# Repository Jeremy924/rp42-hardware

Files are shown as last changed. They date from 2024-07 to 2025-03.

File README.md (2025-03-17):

# RP-42
The goal of RP-42 is to develop an affordable calculator that can run [Free42](https://github.com/Jeremy924/free42). The target cost for this was initially $20, but the final calculator costs slightly under $30. <br>
The calculator uses a STM32L475 microcontroller connected to a 8MB QSPI Flash. The operating system is stored on the STM32's internal 256KB Flash, while the Free42 application code is stored on the external flash drive. The QSPI interface can be memory mapped on the STM32, so the application code can be executed on the flash drive without copying to the RAM. 
<br><br>
More information about RP-42 can be found on the RP-42 website [here](https://jeremy924.github.io/rp42/index.html).

## Development Timeline
07/06/2024 - Started designing PCB<br>
07/29/2024 - Completed PCB 0.0.4, and ordered PCB through JLCPCB<br>
08/04/2024 - Used Raspberry PI Zero 2W and ESP32-S3 to display Free42 on the LCD screen used in the calculator<br>
08/05/2024 - Began assemblying and testing<br>
08/11/2024 - STM32 communicates through micro USB port for the first time<br>
08/11/2024 - Test code is executed on the microcontroller, which showed that all the buttons and the LCD were working correctly. <br>

<br>
<i>In the test shown above, whenever a key is pressed, the number corresponding to the key that was pressed was displayed on the screen. The image shows that all the buttons were read correctly by the microcontroller.</i>
<br>The jumper wire in the image above is used to connect the UART RX pin to either GND or 3V. In the original PCB design, the BOOT0 pin on the STM32 was directly connected to 3V, however this did
not work because BOOT0 must be low in order to execute user code, even if the USB DFU is used to execute code. To correct this issue, the trace connected to the BOOT0 was broken, and the trace connected to the UART RX pin was broken. Because the traces were very close to each other, some solder was used to bridge the gap between the UART port and the BOOT0 pin. This way, the UART RX connector could be 
used to pull BOOT0 to low or high. 
<br><br>
08/21/2024 - STM32 can read and write to Flash drive through QSPI interface. <br>
08/21/2024 - Set up basic command line interface over USB VCP to make debugging easier, and created "frw" (flash read-write tool) to control flash. <br>

<br><i>In the test shown above, the flash read-write tool was used to write "Hello world" to the flash and then read it back. The test shows that the hardware and software for the flash is working correctly</i><br>
12/10/2024 - Complete 0.0.5 and order PCB <b>with SWD port</b><br>
01/22/2025 - Ran Free42 on RP42. <br>

<br>

## Schematics for 0.0.5
### Top Module

### Keyboard

### Screen

### MCU

### Power Components

### PCB 0.0.5


## Hardware Changes for version 0.0.6
- [ ] Move COL0 input to a pin supporting powerdown interrupt.
## Hardware Changes for version 0.0.5
- [X] Add pad for battery terminal
      - temporary solution for 0.0.4: scrape off surface to access battery trace
- [X] Add button for BOOT0
      - temporary solution for 0.0.4: break current BOOT0 trace and connect it to backup RX trace. Then use RX connector to pull BOOT0 either high or low.
- [X] Add button for RES
      - temporary solution for 0.0.4: disconnect power.
- [X] **Add debug port**
- [X] move buttons closer together
- [X] connect VBAT to 3V rather than directly to battery. In its current state, if USB is connected and battery is not, then VBAT will be 0V, which is outside of recommended operating conditions.
- [X] move components further away from battery so that battery does not hit them if pushed in too far
- [X] add pull up resistor for external flash NCS pin so that it is pulled high while STM32 is booting.
- [X] add pull up resistor for on button so that mcu can be powered off and button will still be able to trigger interrupt

### Software Status
RP-42 is able to perform all mathematical operations in Free42. See (Free42)[github.com/Jerem924/free42) for current status.

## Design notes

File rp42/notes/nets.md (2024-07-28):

# Power Supplies
**VBAT** - 2.7V-3V: power directly from battery<br>
**GND**  - 0V<br>
**3V**   - 2.7V-3V: regulated voltage from USB/battery for mcu<br>
**3V PERPH** - 2.7V-3V: regulated voltage from USB/battery for peripherals<br>
**5V USB**    - 5V: power directly from USB<br>
**3V-5V**     - 2.7V-5V: unregulated power selected from USB if available or battery

# Nets:
### PWR_PERPH
Connections: *mcu* (pin 61/PB8, out), *U5* (PSU, in), R2(PSU,in)<br>
Enables power for the flash and the screen. <br>
Pulled down by a 100K resistor. The output from the mcu
can be in 3 states, high (enable peripherals),
high impedance (pulled low by resistor), or off (also pulled low by resistor).
The mcu pin should not be set to low could possibly be higher than 0V, which would
leak current.
### COL[0..5]
Connections: input_matrix (all buttons, out), mcu(pins 8-11,24,25/PC0-PC6, in)<br>
Pins are normally high impedance, so they should be pulled low by the mcu. If button is
pressed while mcu is scanning keyboard, then high output from ROW will pull the pin high.
### ROW[0..6]
Connections: input_matrix (all buttons, in), mcu(pins 13-20,31,43/PA0-PA4,PA8,PA10,out)<br>
Pins should normally be high impedance, except when scanning. When scanning, all pins should be 
low except for the pin that is currently being scanned. 
### ~RES
Connections: U1 (pin 39,in),mcu(pin 35/PB14,out)<br>
Used to reset the screen
### ~CS
Connections: U1 (pin 40,in),mcu(pin 34/PB13,out)<br>
Used to select the screen. This will probably always be low.
### ~A0
Connections: U1 (pin 38,in),mcu(pin 33/PB12,out)<br>
Used to select the address or data mode of the screen.
### SCL
Connections: U1 (pin 37,in),mcu(pin 51/PC10,out)<br>
Used to clock data into the screen.
### SI
Connections: U1 (pin 36,in),mcu(pin 53/PC12,out)<br>
Used to send data to the screen.
### D-
Connections: mcu (pin 44/PA11,io), CR1(pin 3,io)<br>
USB minus data. 
### D+
Connections: mcu (pin 45/PA12,io), CR1(pin 1,io)<br>
USB plus data.
### FLASH_IO[0..3]
Connections: mcu (pin 27/PB1,pin 26/PB0,pin 23/PA7,pin 22/PA6,io), U3(pin 5,2,3,7,io)<br>
Used to communicate with the flash chip.
### FLASH_NCS
Connections: mcu (pin 30/PB11,out), U3(pin 1,in)<br>
Used to select the flash chip.
### FLASH_CLK
Connections: mcu (pin 29/PB10,out), U3(pin 6,in)<br>
Used to clock data into the flash chip.
### D- IN
Connections: J1 (pin 2,io), CR1 (pin 4,io)<br>
USB minus data input. This is sent to the esd protection chip before 
going to the mcu.
### D+ IN
Connections: J1 (pin 3,io), CR1 (pin 6,io)<br>
USB plus data input. This is sent to the esd protection chip before
going to the mcu.

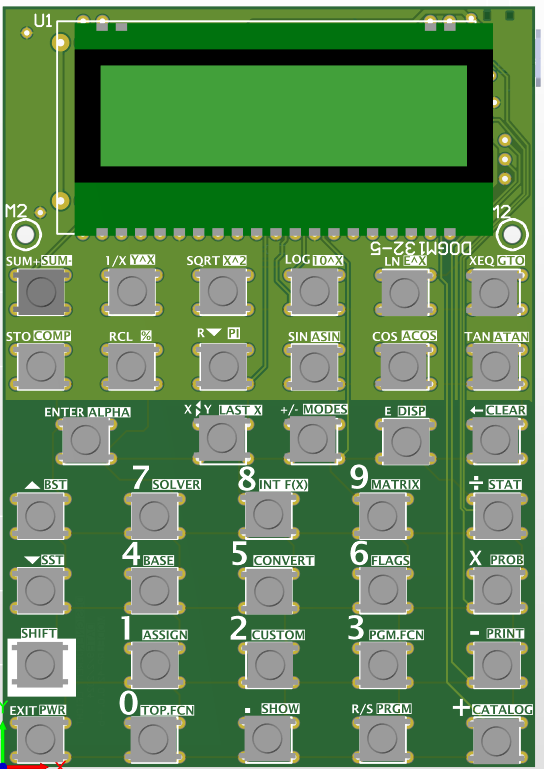
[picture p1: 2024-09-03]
docs/img/altuim-3d-front.png

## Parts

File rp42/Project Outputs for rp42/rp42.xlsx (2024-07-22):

Line # | Name | Description | Designator | Quantity | Manufacturer 1 | Manufacturer Part Number 1 | Manufacturer Lifecycle 1 | Supplier 1 | Supplier Part Number 1 | Supplier Unit Price 1 | Supplier Subtotal 1
 | 1uF | CL10B105KP8NNNC | C1, C2, C3, C4, C5, C6, C7, C8, C9, C10, C17, C18, C19, C20 | 14
 | 20pF | SMD Capacitor C0G(EIA) with Capacitance: 20pF Tol. 5%. Rated Voltage: 50Vdc GRM0335C1H200JA01D | C11, C12 | 2
 | 100nF | 0.1ÂµF Â±10% 10V Ceramic Capacitor X7R 0402 _1005 Metric_ | C13, C14, C15, C16 | 4
 | USBLC6-4SC6 | No Description Available | CR1 | 1
 | 10118192-0002LF | Micro USB 2.0, Input Output Connectors, B TYPE RECEPTACLE without flange | J1 | 1
 | 470R | RC0402FR-07470RL 470R smd resistor | R1 | 1
 | 100K | RC0402FR-07100KL | R2 | 1
 | temp_switch |  | S1, S2, S3, S4, S5, S6, S7, S8, S9, S10, S11, S12, S13, S15, S16, S17, S18, S19, S20, S21, S22, S23, S24, S25, S26, S27, S28, S29, S30, S31, S32, S33, S34, S35, S36, S37, S38, S39, S40, S41, S42 | 41
 | INTERFACE |  | U1 | 1
 | STM32L475RCT3 | No Description Available | U2 | 1
 | W25Q64JVSSIQ | No Description Available | U3 | 1
 | MIC5365-3.0YC5-TR | 3V Linear Voltage Regulator | U4, U6 | 2
 | TPS2115PW | 2.8-V to 5.5-V, 84-m&Omega;, 1.25-A, power mux with manual, automatic, slow switchover and status | U5 | 1
 | 8.000MHZ | HC/49US (AT49) SMD LOW PROFILE CRYSTAL ABLS-8.000MHZ-B4-T | Y1 | 1

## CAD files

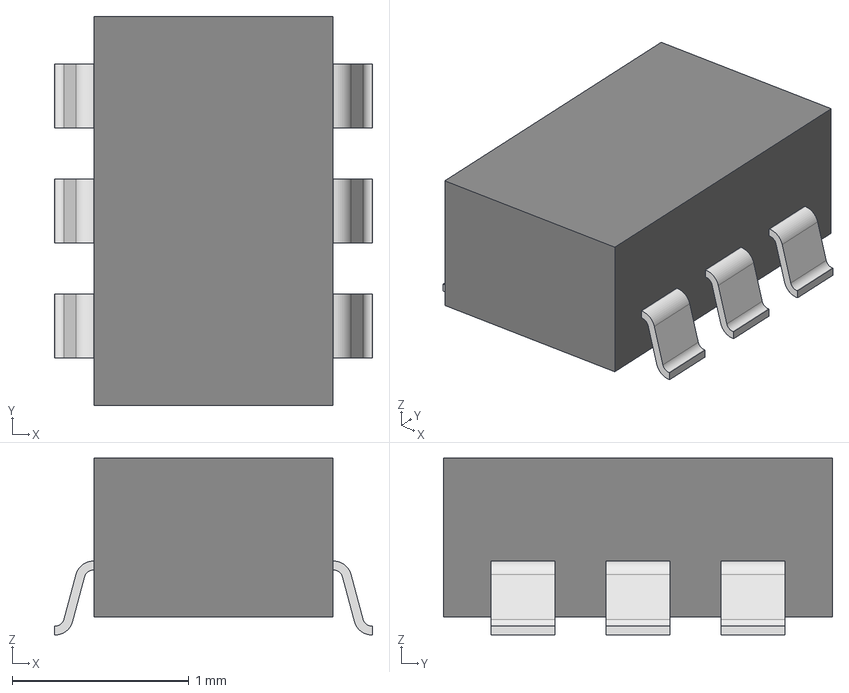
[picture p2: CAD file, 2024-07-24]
rp42/BAT54DW_7_F/AltiumDesigner/SOT-363_DIO.step
1.80 x 2.20 x 1.00 mm

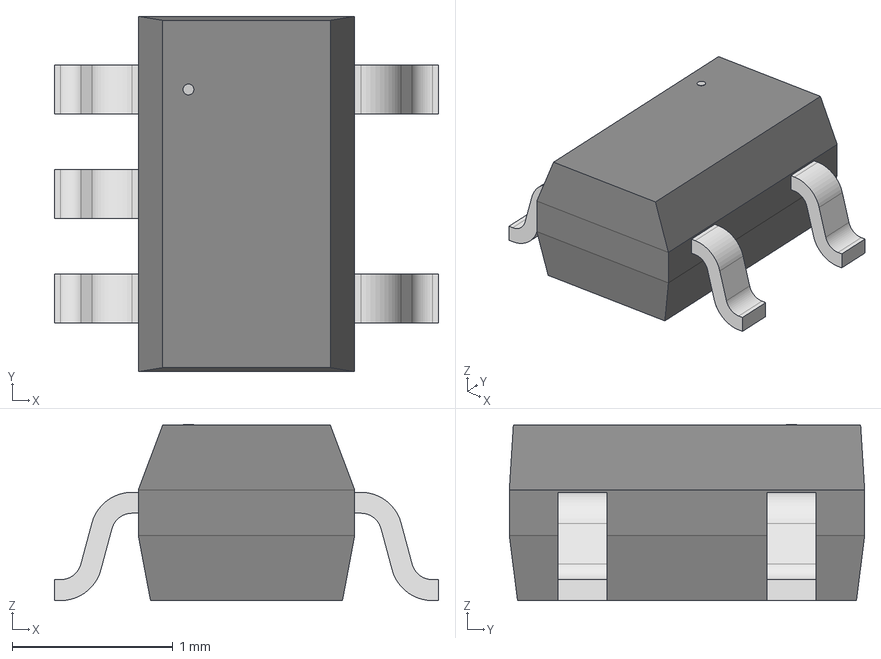
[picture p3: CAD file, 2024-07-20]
rp42/MIC5365_3_0YC5_TR/AltiumDesigner/SC-70_C5_MCH.step
2.39 x 2.21 x 1.09 mm

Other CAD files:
rp42/BAT54DW_7_F/SOT-363_DIO.stl
rp42/MIC5365_3_0YC5_TR/SC-70_C5_MCH.stl

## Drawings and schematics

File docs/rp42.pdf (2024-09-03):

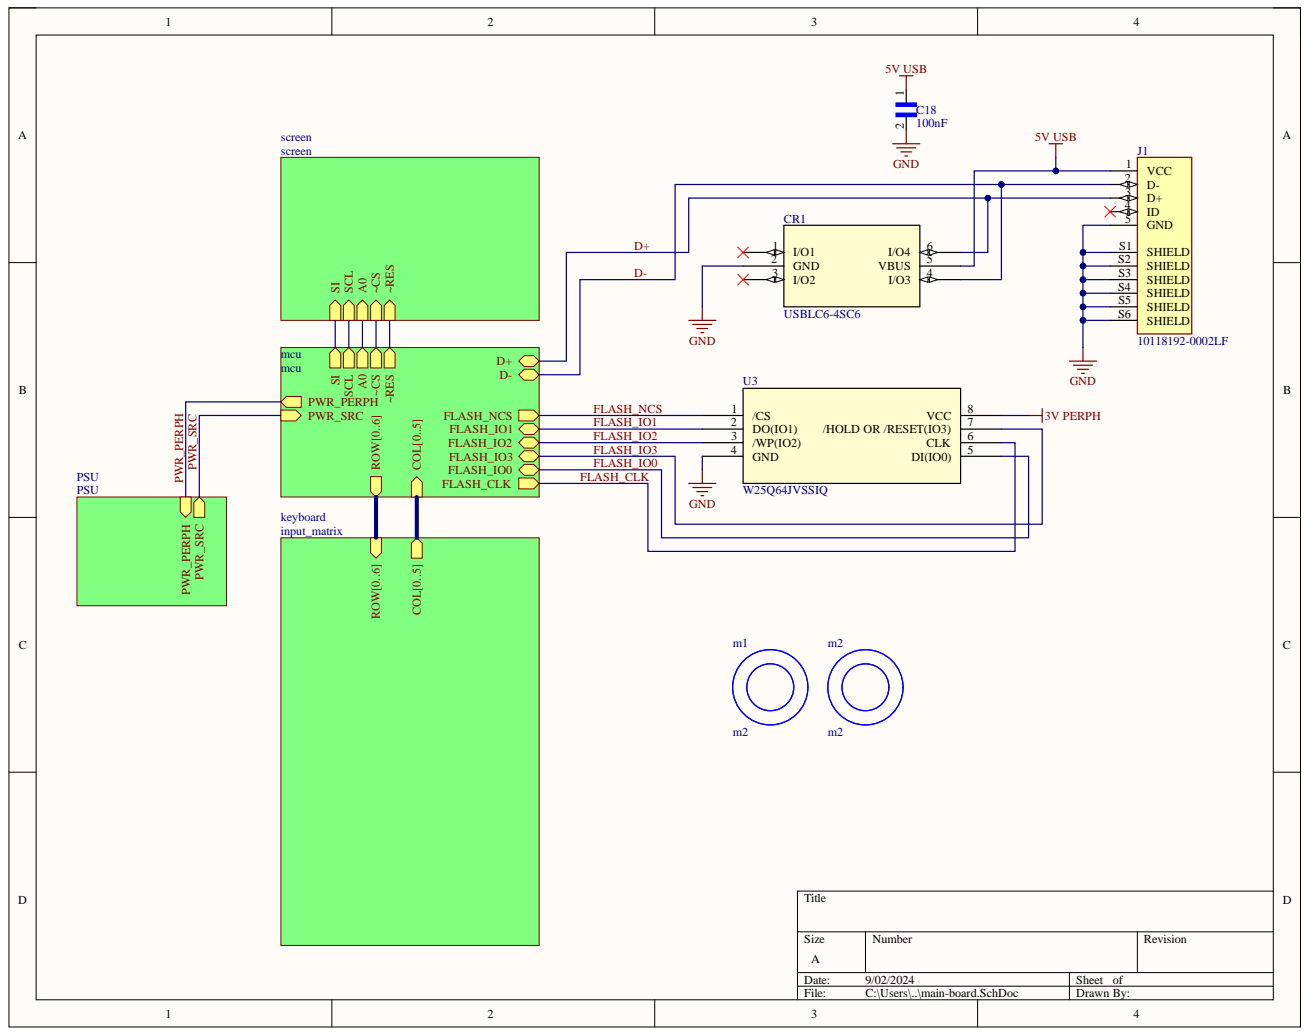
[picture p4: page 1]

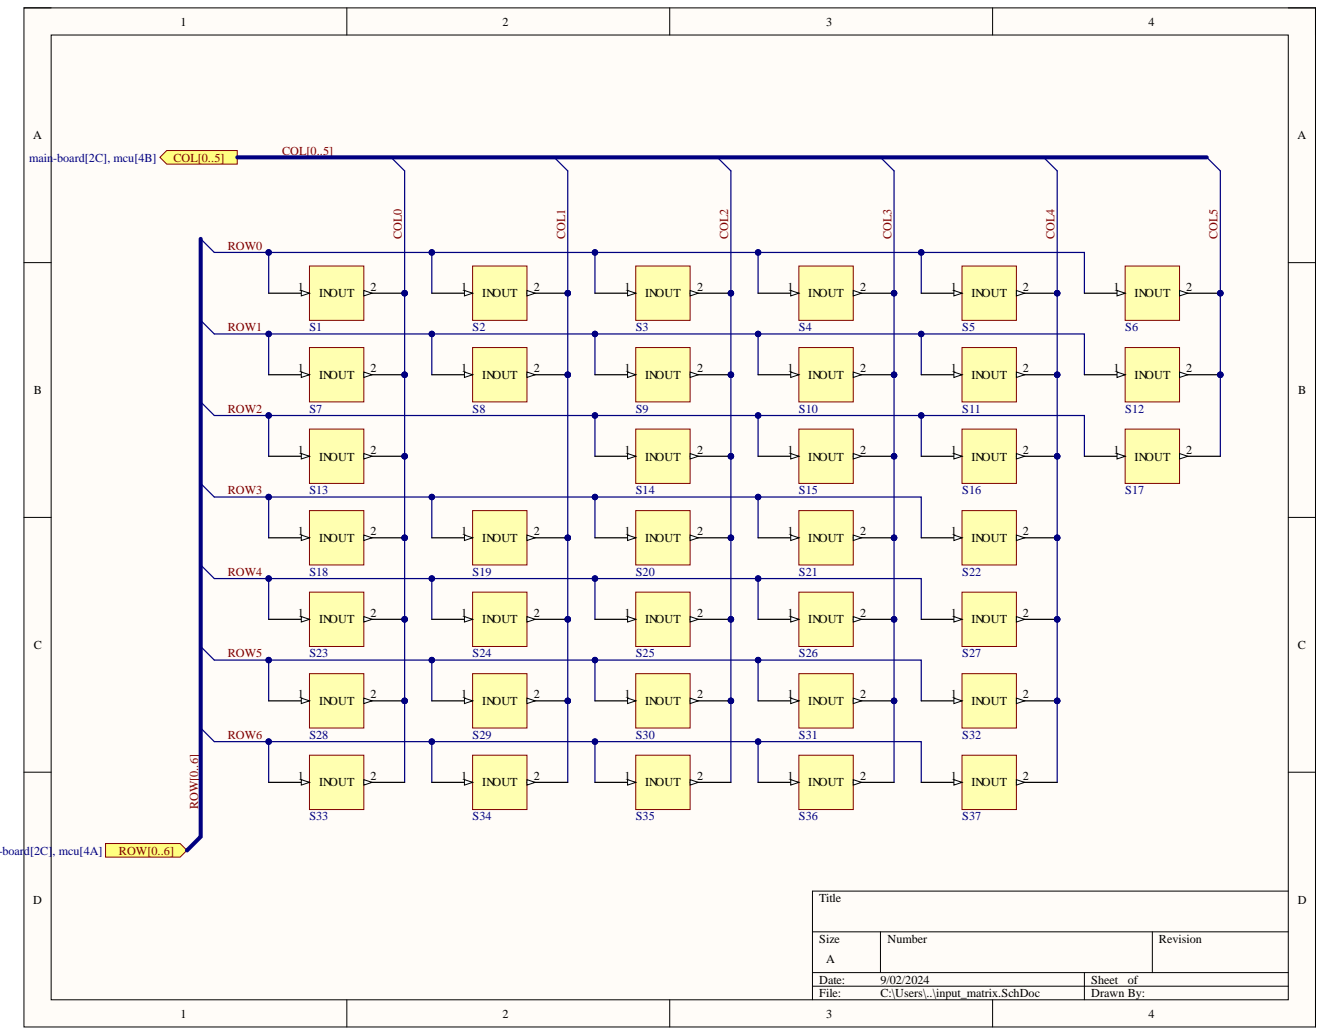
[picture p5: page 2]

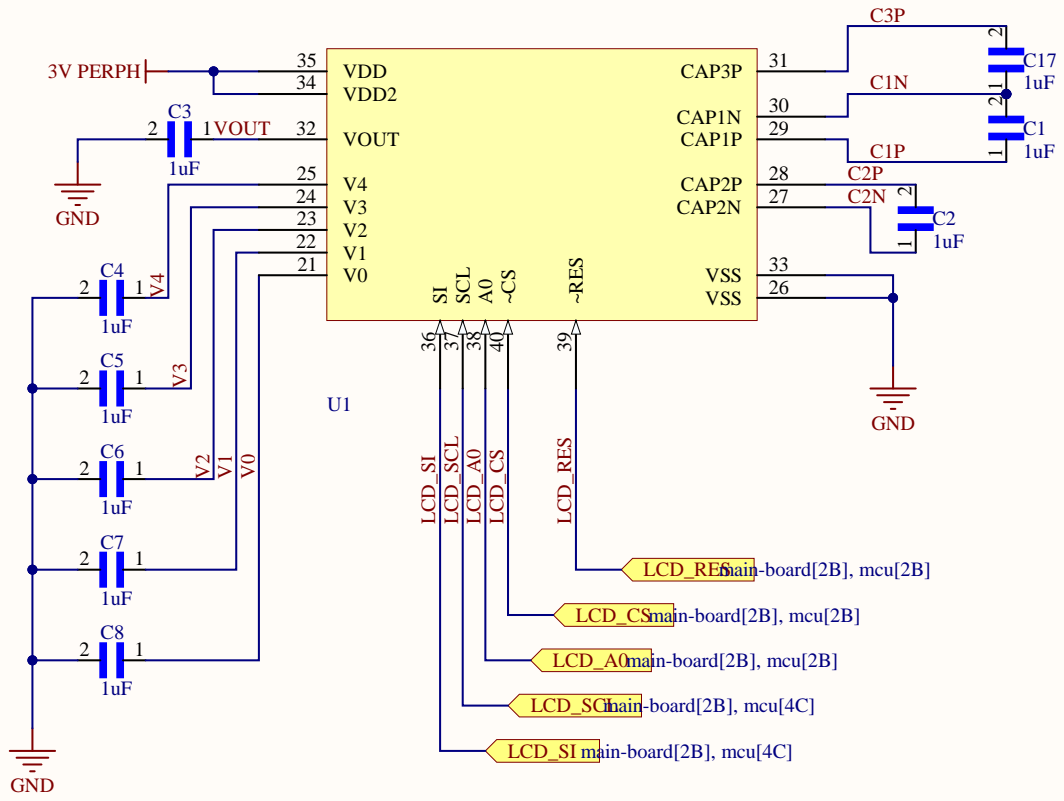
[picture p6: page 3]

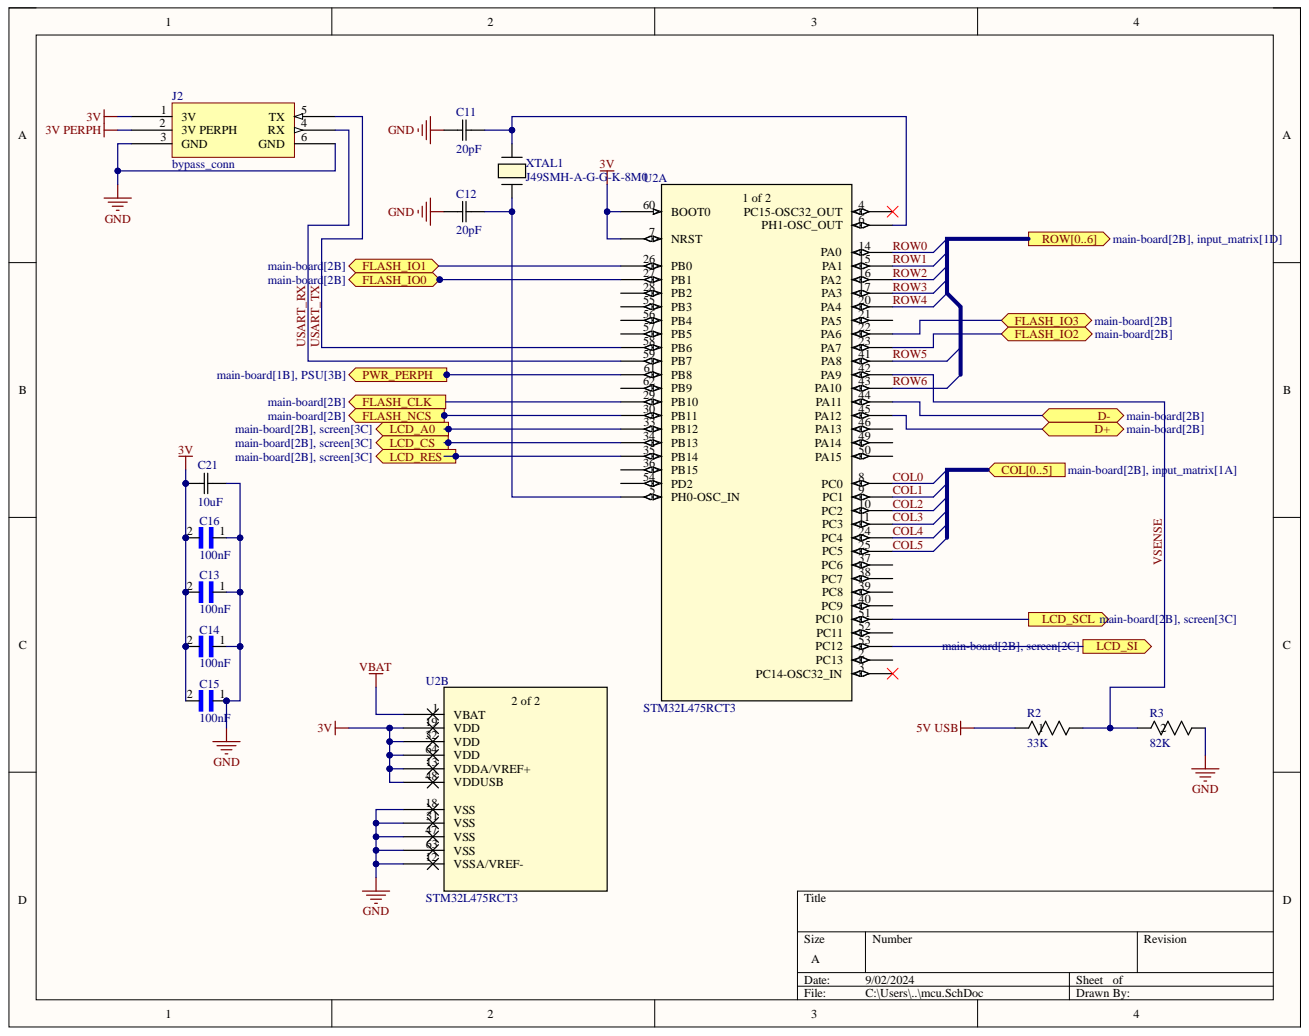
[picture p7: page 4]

PB9 62 | ROW6

PB13 34
PB14 35
PB15 36

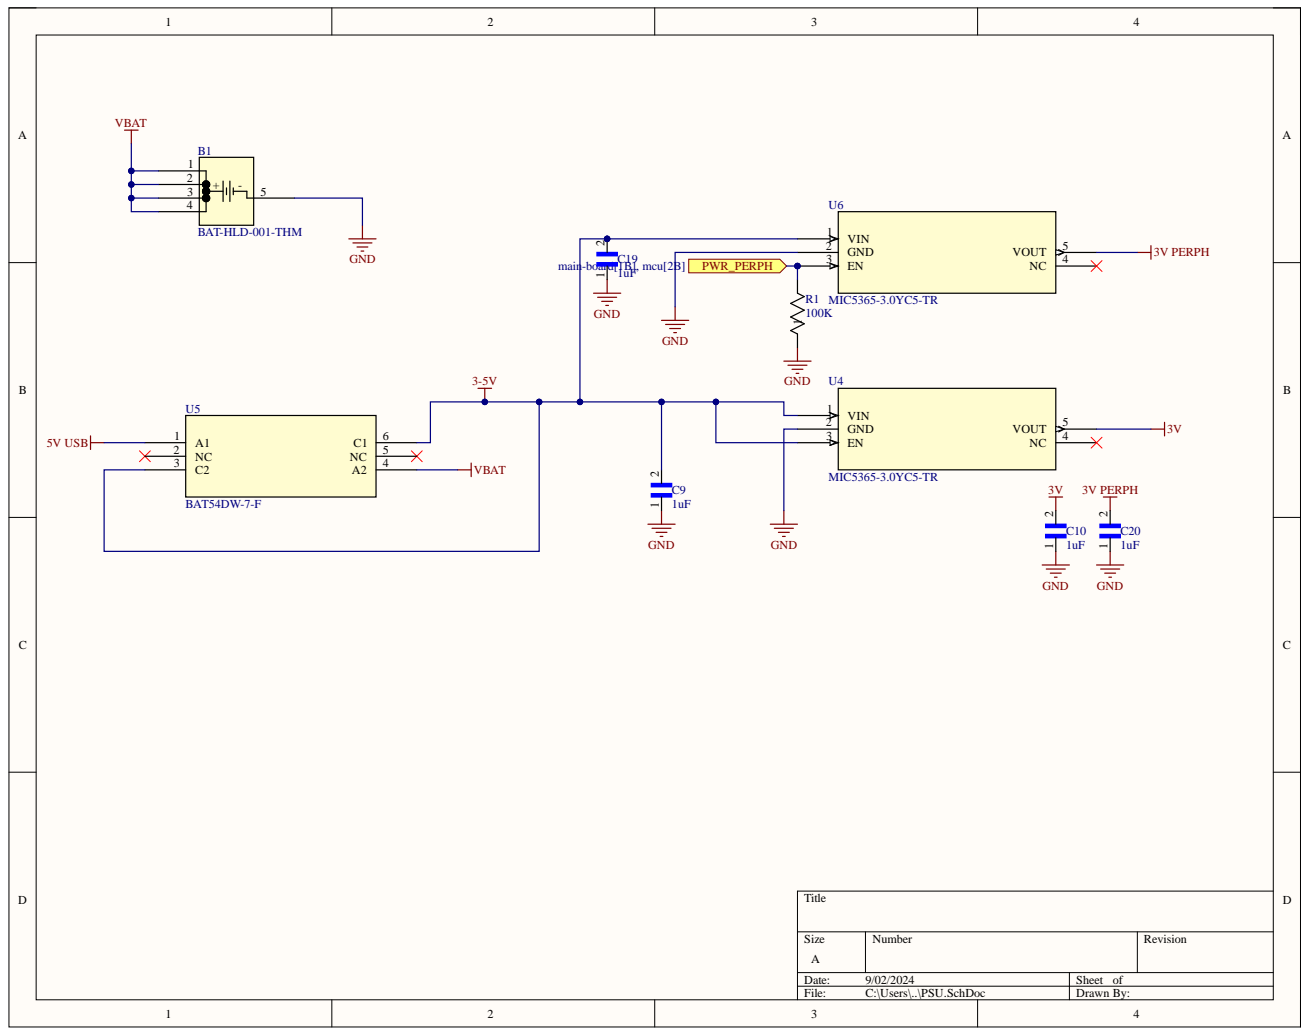
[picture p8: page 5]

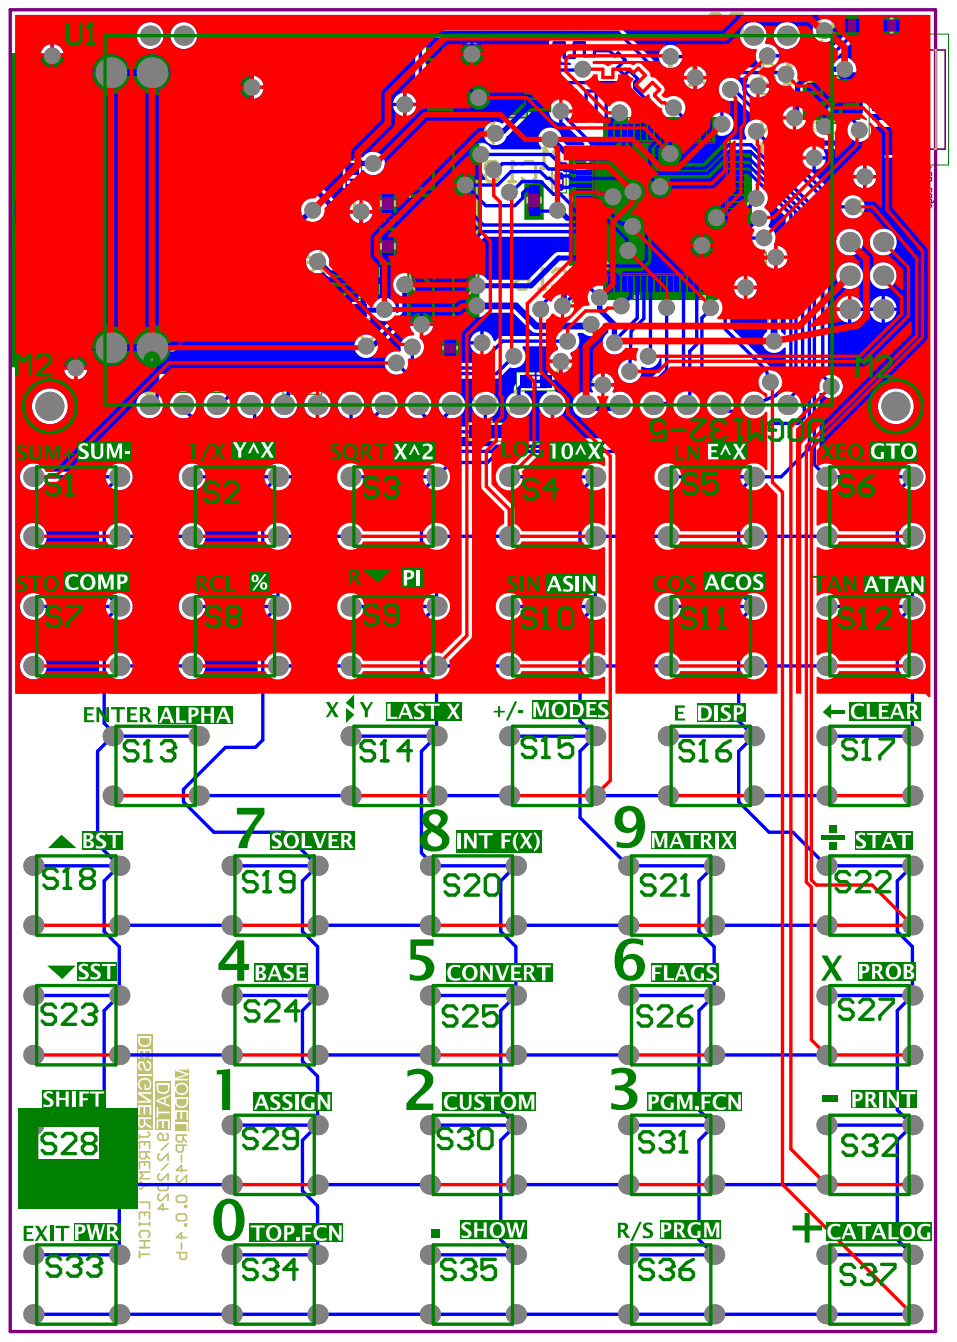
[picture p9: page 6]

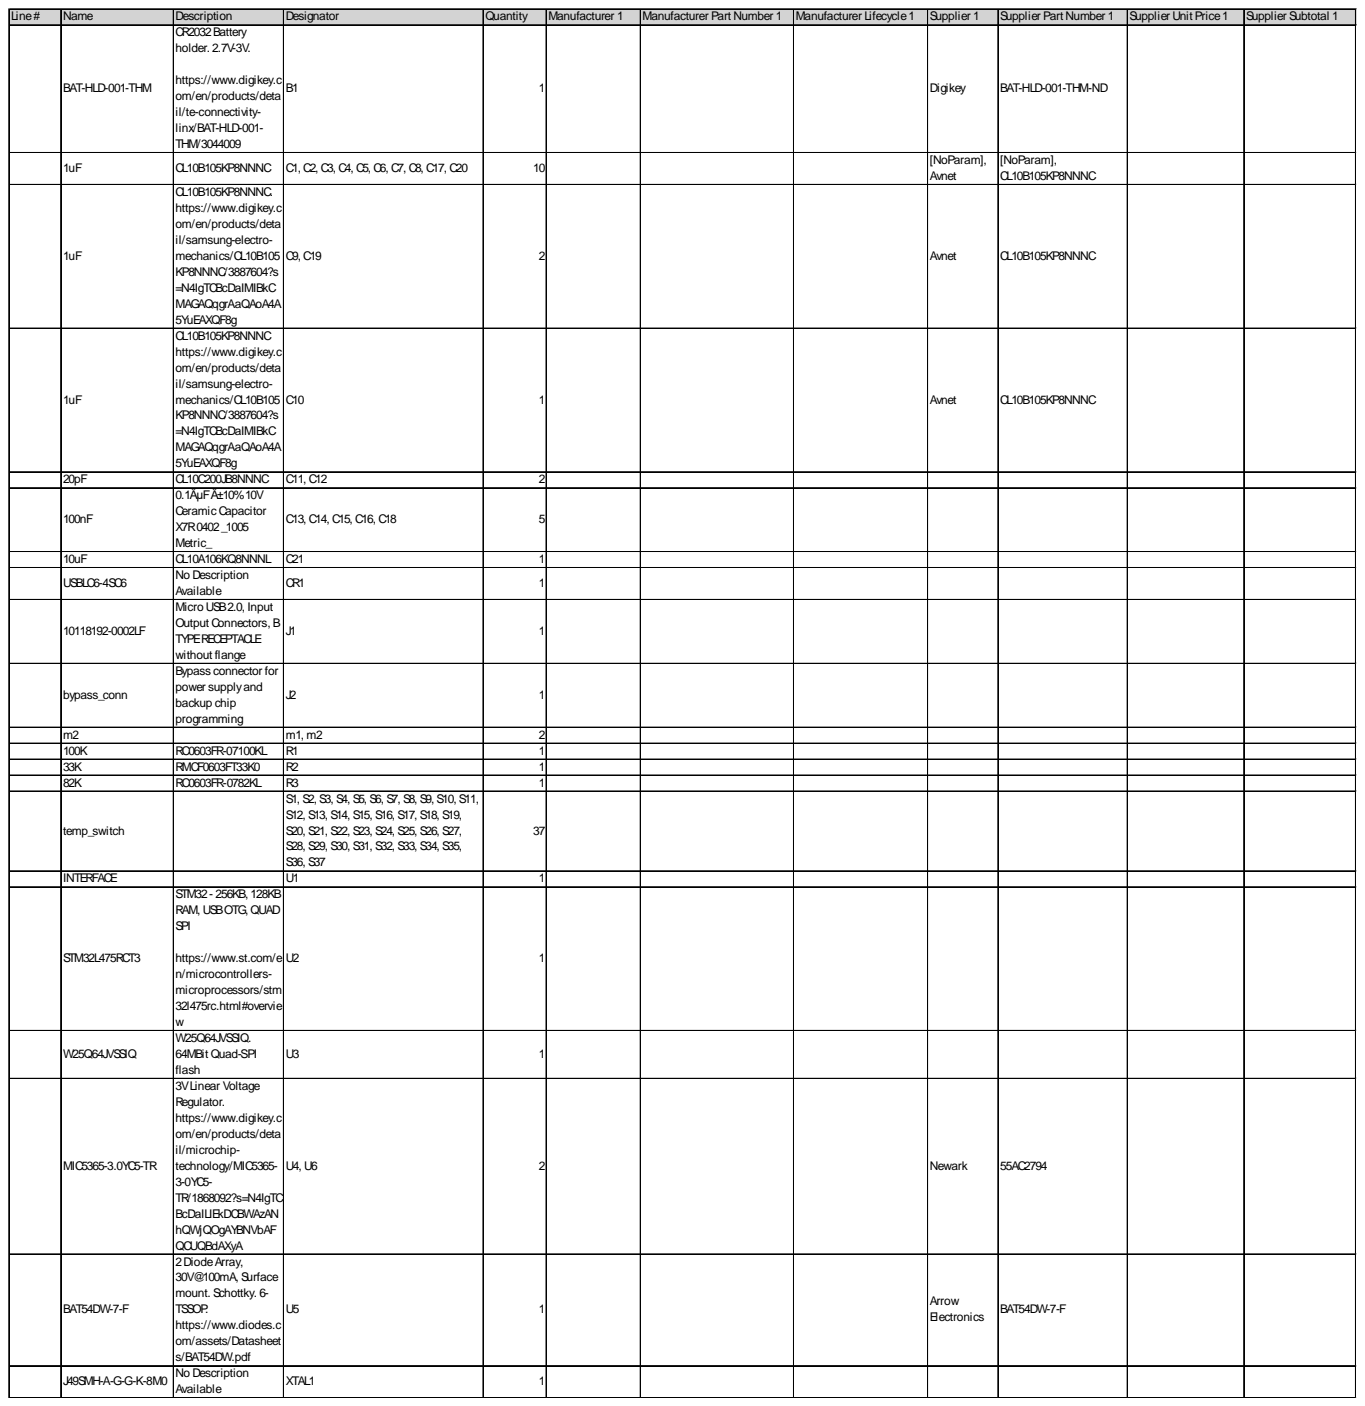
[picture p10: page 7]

Line# | Name | Description | Designator | Quantity | Manufacturer 1 | Manufacturer Part Number 1 | Manufacturer Lifecycle1 | Supplier 1 | Supplier Part Number 1 | Supplier Unit Price1 | Supplier Subtotal 1

BAT-HLD-001-THM | CR2032Battery holder. 2.7V-3V. https://www.digikey.com/en/products/detail/te-connectivity-linx/BAT-HLD-001-THM/3044009 | B1 | 1 | | | | Digikey | BAT-HLD-001-THM-ND

1uF | CL10B105KP8NNNC | C1, C2, C3, C4, C5, C6, C7, C8, C17, C20 | 10 | | | | [NoParam], Avnet | [NoParam], CL10B105KP8NNNC

1uF | CL10B105KP8NNNC. https://www.digikey.com/en/products/detail/samsung-electro-mechanics/CL10B105KP8NNNC/3887604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 MAGAQqgrAaQAoA4A 5YuEAXQF8g | C9, C19 | 2 | | | | Avnet | CL10B105KP8NNNC

1uF | CL10B105KP8NNNC https://www.digikey.com/en/products/detail/samsung-electro-mechanics/CL10B105KP8NNNC/3887604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 MAGAQqgrAaQAoA4A 5YuEAXQF8g | C10 | 1 | | | | Avnet | CL10B105KP8NNNC

20pF | CL10C200JB8NNNC | C11, C12 | 2
100nF | 0.1ÂµFÂ±10%10V Ceramic Capacitor X7R0402_1005 Metric_ | C13, C14, C15, C16, C18 | 5

10uF | CL10A106KQ8NNNL | C21 | 1
USBLC6-4SC6 | No Description Available | CR1 | 1

10118192-0002LF | Micro USB2.0, Input Output Connectors, B TYPERECEPTACLE without flange | J1 | 1

bypass_conn | Bypass connector for power supplyand backup chip programming | J2 | 1

m2 | | m1, m2 | 2
100K | RC0603FR-07100KL | R1 | 1
33K | RMCF0603FT33K0 | R2 | 1
82K | RC0603FR-0782KL | R3 | 1
temp_switch | | S1, S2, S3, S4, S5, S6, S7, S8, S9, S10, S11, S12, S13, S14, S15, S16, S17, S18, S19, S20, S21, S22, S23, S24, S25, S26, S27, S28, S29, S30, S31, S32, S33, S34, S35, S36, S37 | 37

INTERFACE | | U1 | 1
STM32L475RCT3 | STM32- 256KB, 128KB RAM, USBOTG, QUAD SPI https://www.st.com/en/microcontrollers-microprocessors/stm 32l475rc.html#overvie w | U2 | 1

W25Q64JVSSIQ | W25Q64JVSSIQ. 64MBit Quad-SPI flash | U3 | 1

MIC5365-3.0YC5-TR | 3VLinear Voltage Regulator. https://www.digikey.com/en/products/detail/microchip-technology/MIC5365-3-0YC5-TR/1868092?s=N4IgTC BcDaILIEkDCBWAzAN hQWjQOgAYBNVbAF QCUQBdAXyA | U4, U6 | 2 | | | | Newark | 55AC2794

BAT54DW-7-F | 2DiodeArray, 30V@100mA, Surface mount. Schottky. 6-TSSOP. https://www.diodes.com/assets/Datasheets/BAT54DW.pdf | U5 | 1 | | | | Arrow Electronics | BAT54DW-7-F

J49SMH-A-G-G-K-8M0 | No Description Available | XTAL1 | 1

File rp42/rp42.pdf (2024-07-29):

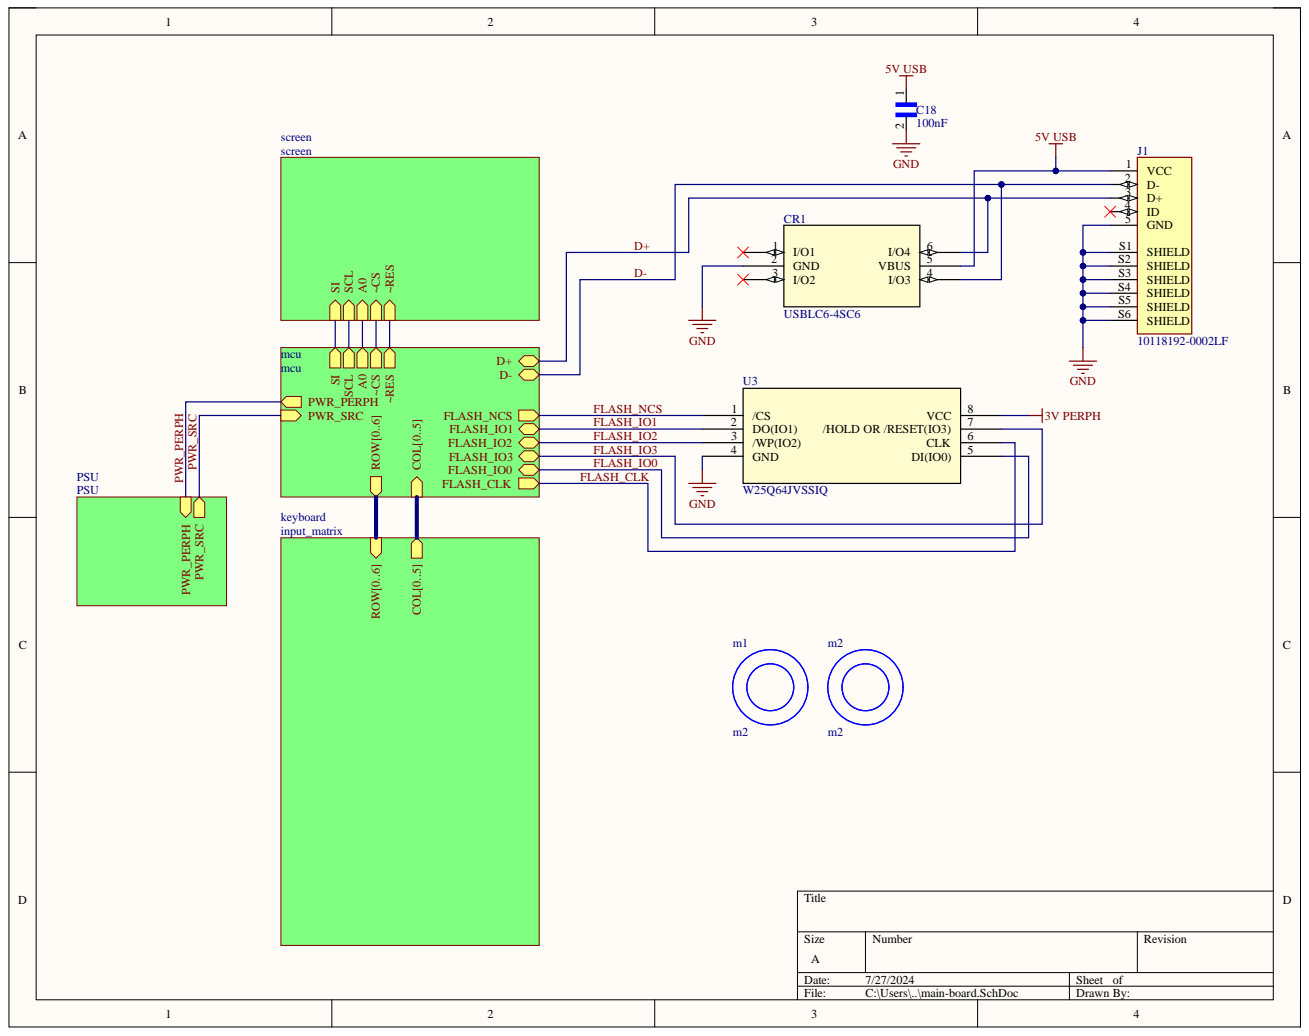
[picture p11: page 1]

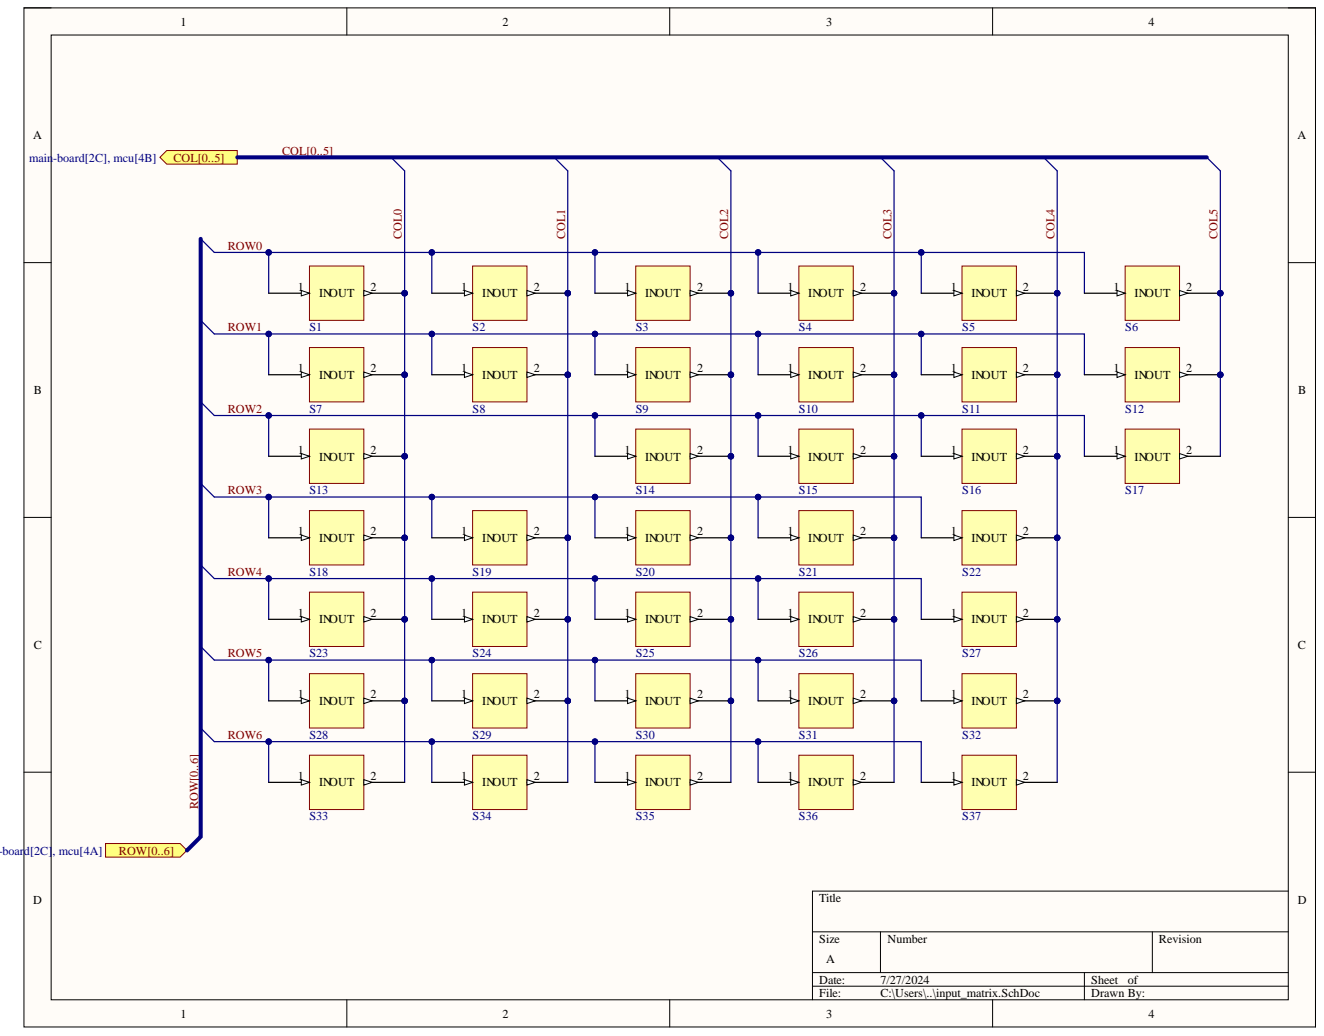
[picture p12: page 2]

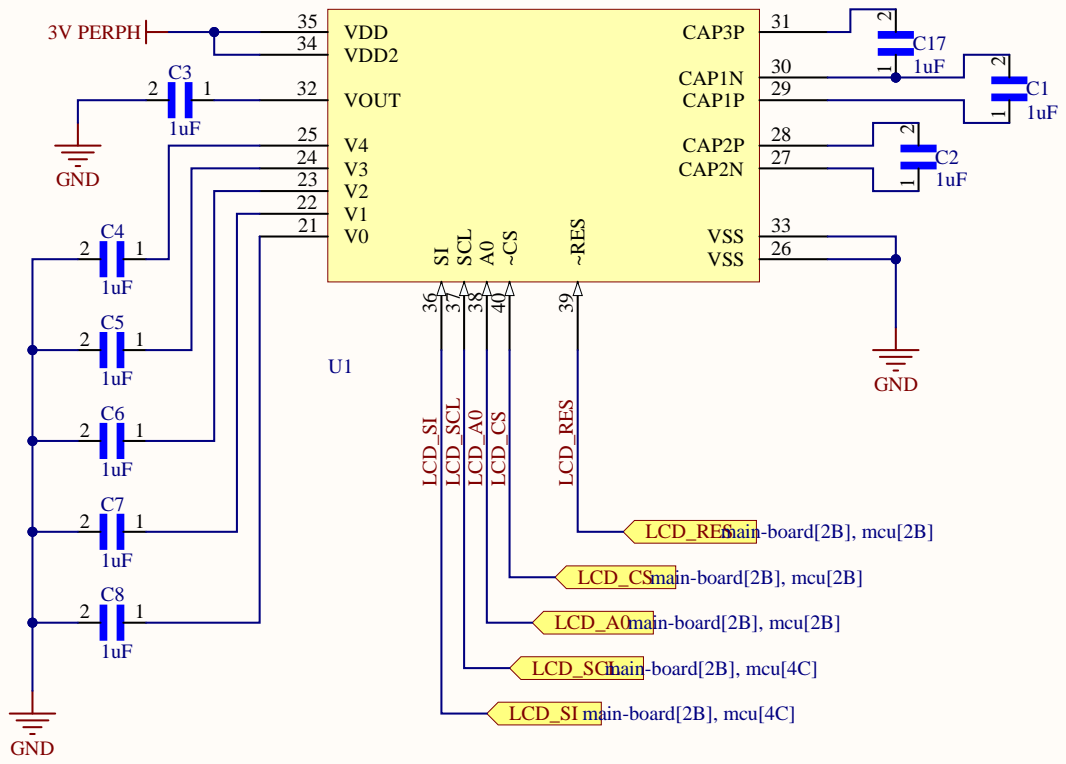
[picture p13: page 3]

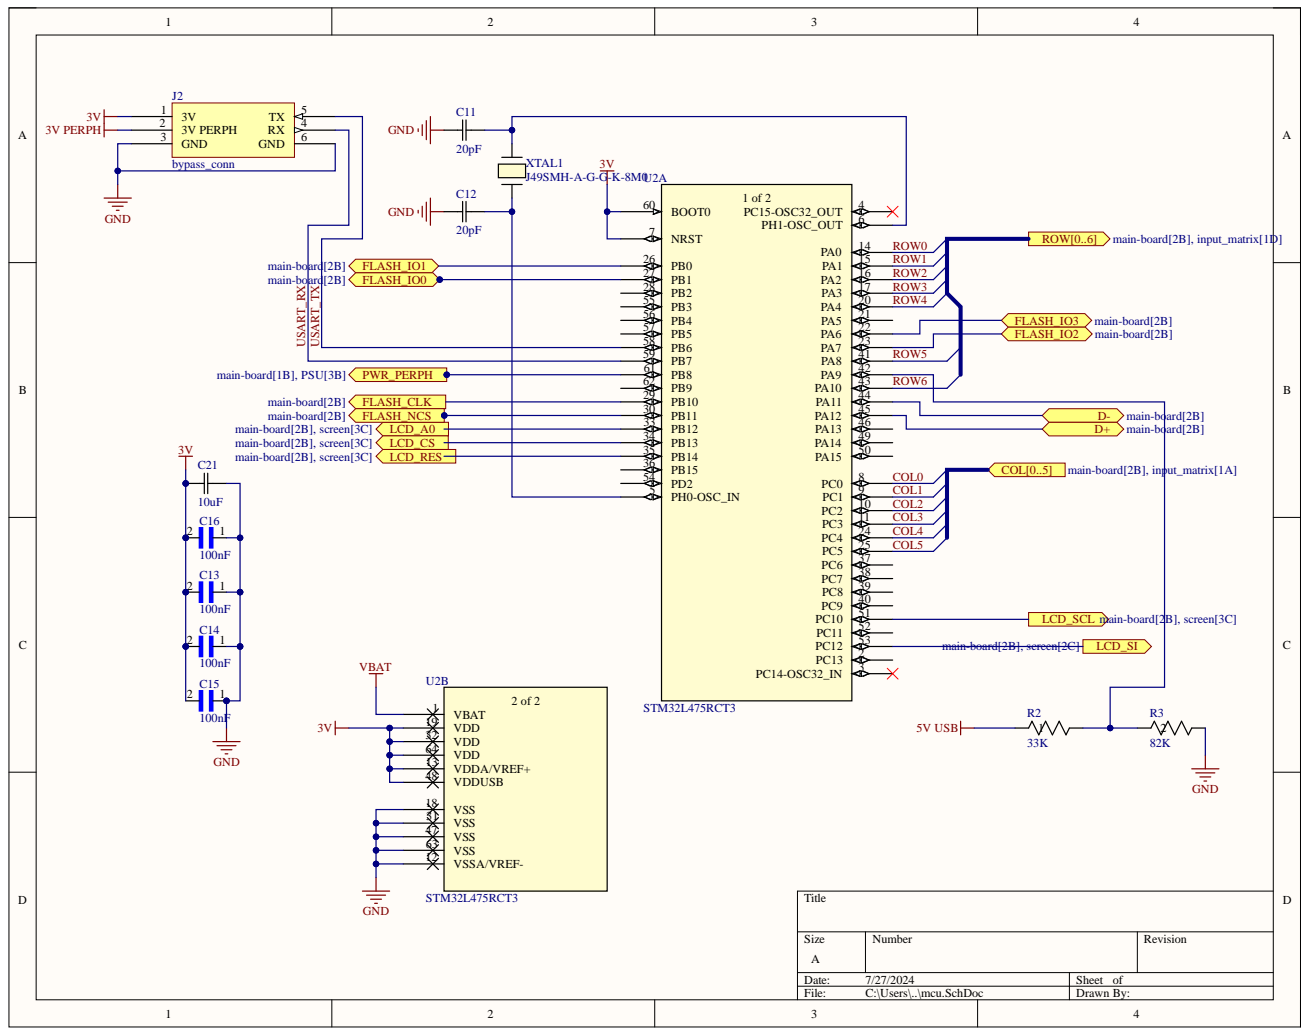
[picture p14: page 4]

PB9 62 | ROW6

PB13 34
PB14 35
PB15 36

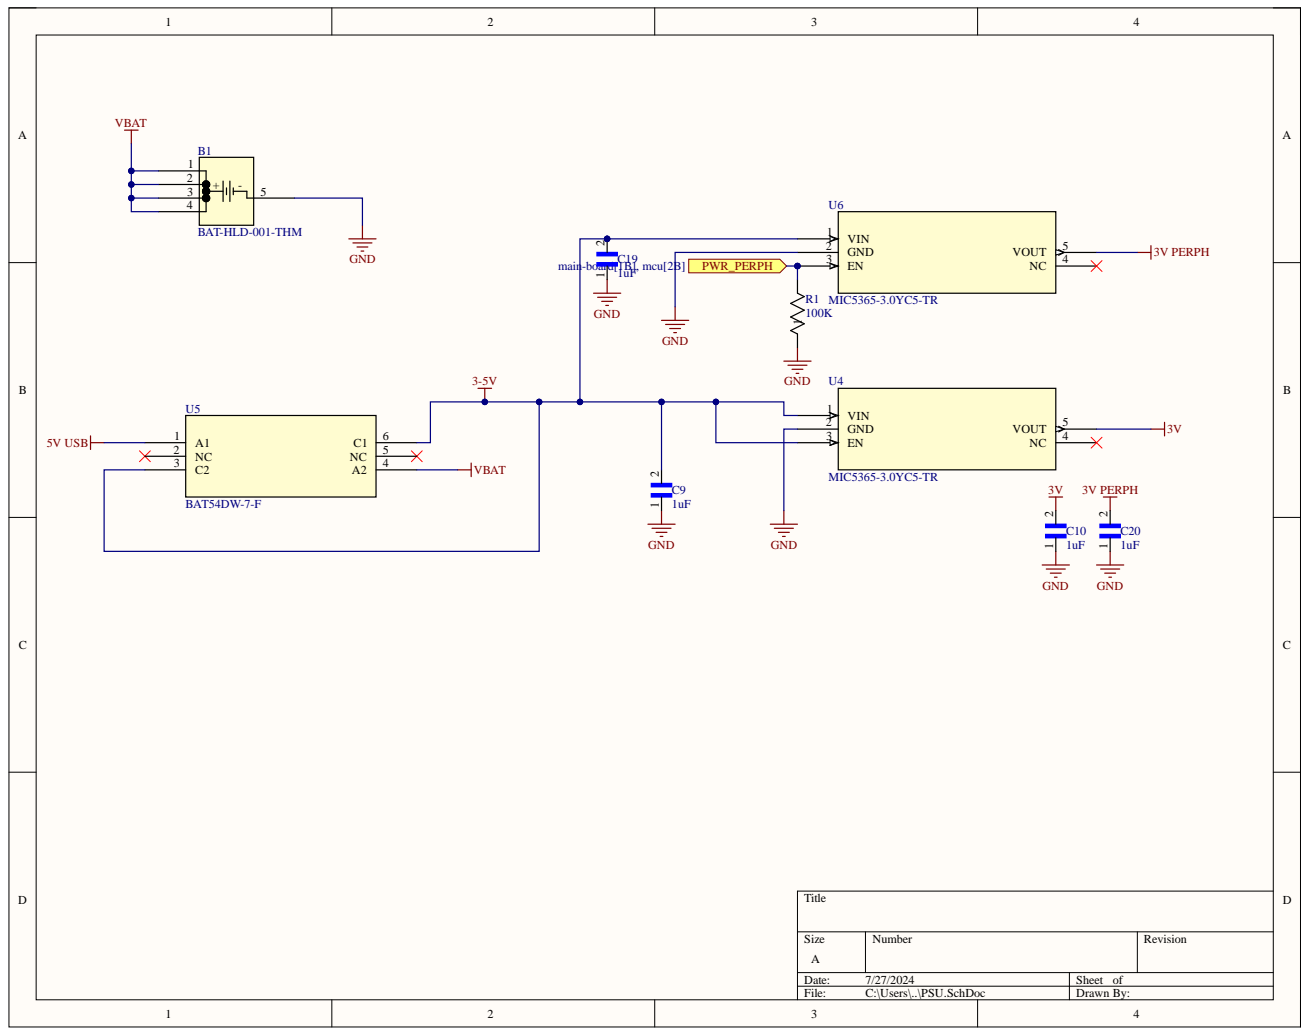
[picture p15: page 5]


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

1uF | CL10B105KP8NNN C | C1, C2, C3, C4, C5, C6, C7, C8, C17, C20 | 10 | | | | [NoParam], Avnet | [NoParam], CL10B105KP8NNNC

1uF | CL10B105KP8NNN C. https://www.digikey.com/en/products/detail/samsu ng-electro-mechanics/CL10B 105KP8NNNC/388 7604?s=N4IgTCBc DaIMIBkCMAGAQ qgrAaQAoA4A5Yu EAXQF8g | C9, C19 | 2 | | | | Avnet | CL10B105KP8NNNC

1uF | CL10B105KP8NNN C https://www.digikey.com/en/products/detail/samsu ng-electro-mechanics/CL10B 105KP8NNNC/388 7604?s=N4IgTCBc DaIMIBkCMAGAQ qgrAaQAoA4A5Yu EAXQF8g | C10 | 1 | | | | Avnet | CL10B105KP8NNNC

20pF | CL10C200JB8NNN C | C11, C12 | 2

100nF | 0.1ÂµFÂ±10%10V Ceramic Capacitor X7R 0402_1005 Metric_ | C13, C14, C15, C16, C18 | 5

USBLC6-4SC6 | No Description Available | CR1 | 1

10118192-0002LF | Micro USB2.0, Input Output Connectors, B TYPERECEPTACLE without flange | J1 | 1

bypass_conn | Bypass connector for power supply and backup chip programming | J2 | 1

m2 | | m1, m2 | 2
100K | RC0603FR-07100KL | R1 | 1

33K | RMCF0603FT33K0 | R2 | 1
82K | RC0603FR-0782KL | R3 | 1

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

EADOGM132W | EADOGM132W. https://www.digikey.com/en/products/detail/display-visions/EA-DOGM132L-5/4896710 | U1 | 1

STM32L475RCT3 | STM32- 256KB, 128KBRAM, USB OTG, QUADSPI https://www.st.com/en/microcontr ollers-microprocessors/ stm32l475rc.html #overview | U2 | 1

W25Q64JVSSIQ | W25Q64JVSSIQ. 64MBit Quad-SPI flash | U3 | 1

MIC5365-3.0YC5-TR | 3VLinear Voltage Regulator. https://www.digikey.com/en/products/detail/microc hip-technology/MIC53 65-3-0YC5-TR/1868092?s=N4I gTCBcDaILIEkDCB WAzANhQWjQOg AYBNVbAFQCUQB dAXyA | U4, U6 | 2 | | | | Newark | 55AC2794

BAT54DW-7-F | 2DiodeArray, 30V@100mA, Surfacemount. Schottky. 6-TSSOP. https://www.diodes.com/assets/Datasheets/BAT54D W.pdf | U5 | 1 | | | | Arrow Electronics | BAT54DW-7-F

J49SMH-A-G-G-K-8M0 | No Description Available | XTAL1 | 1



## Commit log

2024-07-20 added hardware stuff
    [EADOGM132W.PcbLib, EADOGM132W.SchLib, MIC5365-3P0YC5-TR.PcbLib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]
2024-07-22 saved work before altium crashes again
    [PSU.SchDoc, backup-connector.PcbLib, backup_connector.SchLib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]
2024-07-22 remade usart connector after Altium crashed
    [bypass_conn.PcbLib, bypass_conn.SchLib, main-board.PcbDoc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]
2024-07-24 about to switch to using diodes instead of power multiplexer
    [PSU.SchDoc, bypass_conn.SchLib, main-board.PcbDoc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]
2024-07-24 finished connecting everything but keyboard?
    [BAT54DW-7-F.PcbLib, BAT54DW-7-F.SchLib, PSU.SchDoc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]
2024-07-24 tried to make quad spi traces same length
    [main-board.GBL, main-board.GBO, main-board.GBP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]
2024-07-26 fixed button model
    [EADOGM132W.SchLib, button.PcbLib, input_matrix.SchDoc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]
2024-07-28 finished 0.0.2a
    [PSU.SchDoc, m2.PcbLib, m2.SchLib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]
2024-07-28 working on design review
    [input_matrix.SchDoc, main-board.PcbDoc, main-board.SchDoc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]
2024-07-29 continuing to do design review
    [Schlib1.SchLib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]
2024-07-29 continuing design review
    [main-board.PcbDoc]
2024-07-30 finished checking routing
    [EADOGM132W.PcbLib, main-board.PcbDoc, mcu.SchDoc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]
2024-07-30 reloaded pours
    [main-board.PcbDoc]
